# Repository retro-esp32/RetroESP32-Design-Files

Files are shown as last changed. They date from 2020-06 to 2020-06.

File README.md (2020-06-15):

# Retro ESP32
> An ESP32 Wrover based Game Boy Pocket ** Hardware Branch **



[]()

## Hardware
> FTDI Solution

Thanks to a recent contribution, we will be testing out the replacement of the CP2104 USB to UART bridge IC with an FTDI FT232RL IC

The FTDI IC is more hand solder friendly than the CP210x QFN series

Here is a teaser of what we are testing

| Top Layout | Bottom Layout |
| --- | --- |
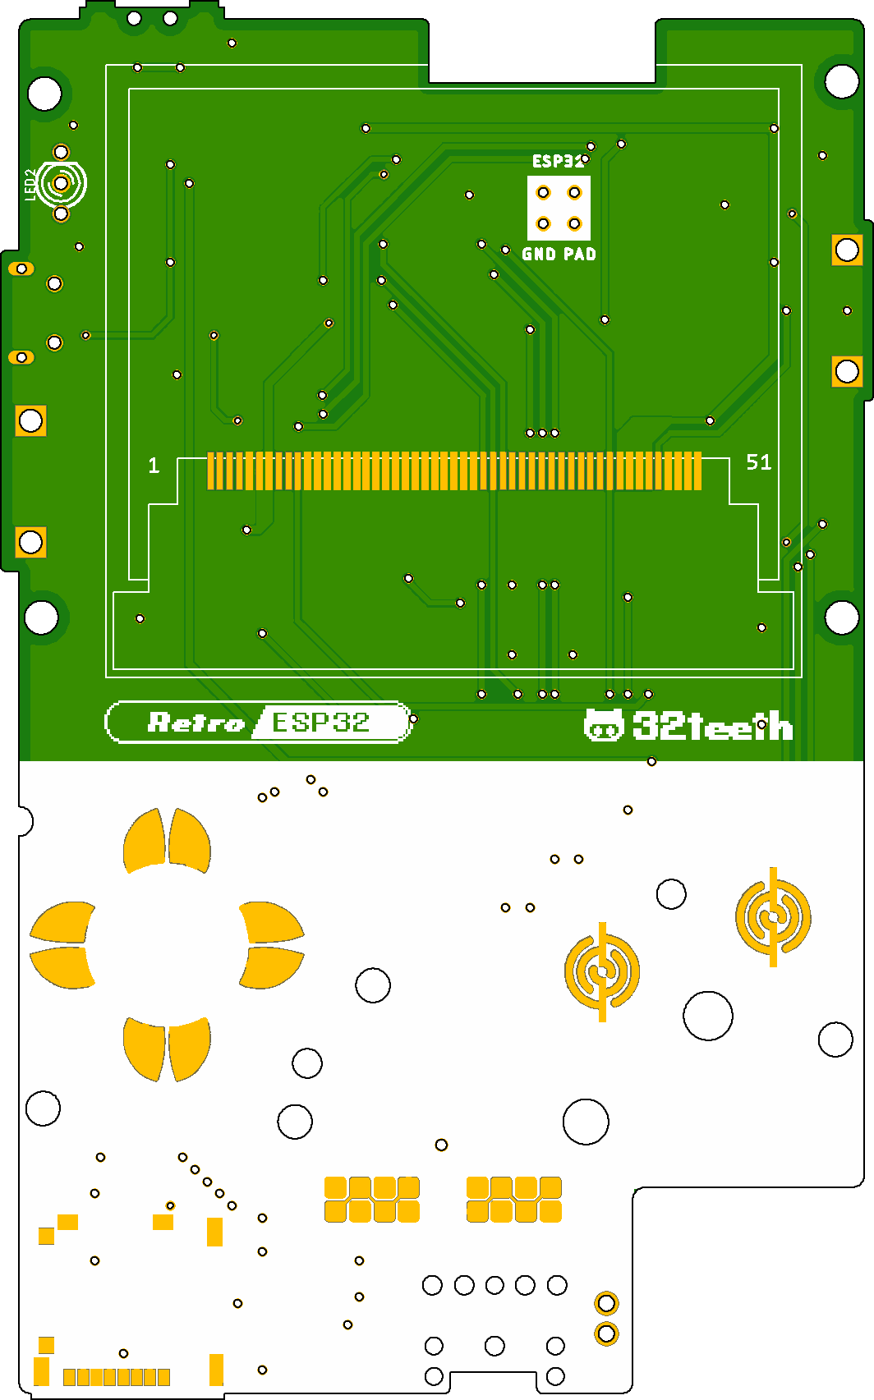
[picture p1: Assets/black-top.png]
Retro ESP32 Top
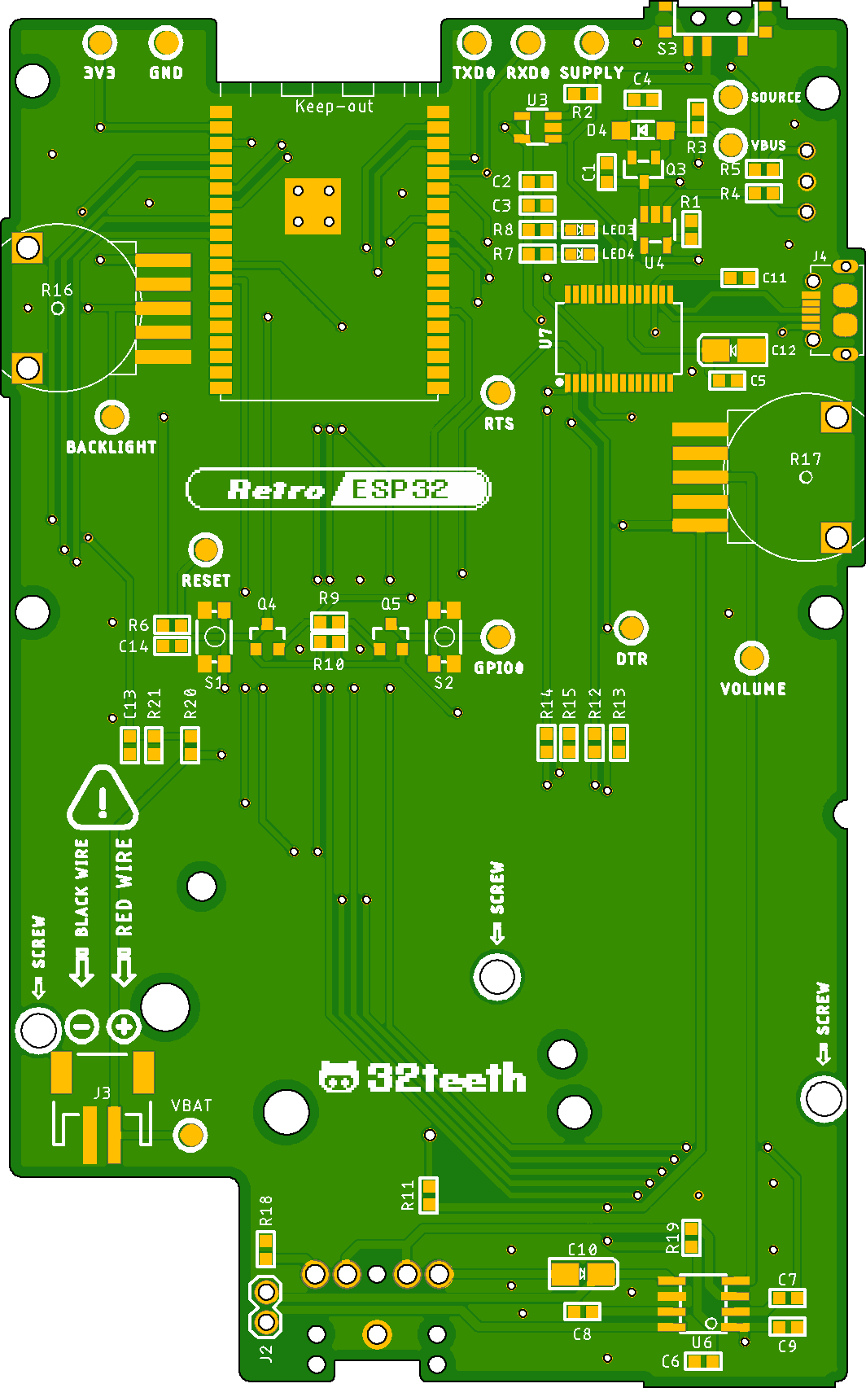
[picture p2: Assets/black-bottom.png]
Retro ESP32 Bottom
|  |  |

## Gerbers
> You can use the Gerber Files to check your production

*note:* PCB thickness must be 1mm

## BOM
> Full Bom Available

*note:* LCD and Thumbwheels have AliExpress Links

### Eagle Library
> We use a Managed Library

[RetroESP32](urn:adsk.eagle:library:12566846)

-----

> ## Although we do this for 💕 of 🕹️
> **We Also Like Coffee!**
> *Please Consider Supporting*<br>
> Support (https://github.com/sponsors/retro-esp32)

-----

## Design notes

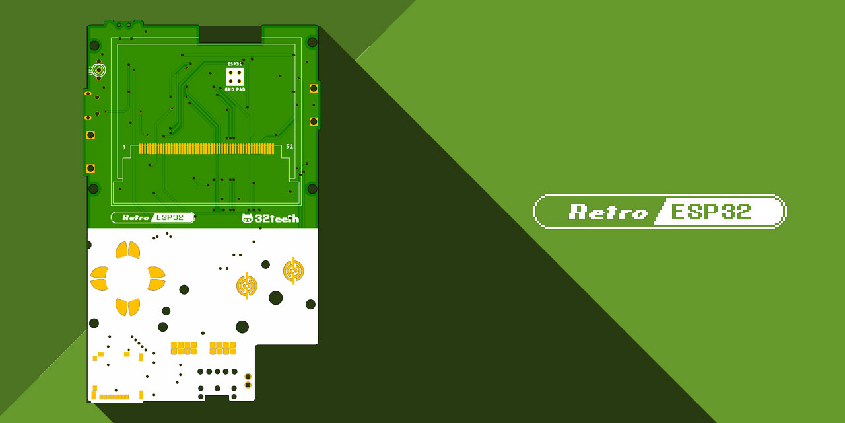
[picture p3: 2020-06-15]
Assets/hardware.jpg

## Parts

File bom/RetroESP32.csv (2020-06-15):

Quantity | Reference Designator | Manufacturer Part Number | Manufacturer | Digi-Key Part Number | Description
4 | C1, C2, C4, C6 | CL10A106MP8NNNC | Samsung Electro-Mechanics | 1276-1871-1-ND | CAP CER 10UF 10V X5R 0603
1 | C10 | F930J107KAA | AVX Corporation | 478-8152-1-ND | CAP TANT 100UF 10% 6.3V 1206
1 | C12 | F930J106MAA | AVX Corporation | 478-8151-1-ND | CAP TANT 10UF 20% 6.3V 1206
4 | C3, C8, C9, C14 | CL10A105KP8NNNC | Samsung Electro-Mechanics | 1276-1182-1-ND | CAP CER 1UF 10V X5R 0603
3 | C5, C11, C13 | CL10B104KB8NNNC | Samsung Electro-Mechanics | 1276-1000-1-ND | CAP CER 0.1UF 50V X7R 0603
1 | C7 | CL10C221JB8NNNC | Samsung Electro-Mechanics | 1276-1048-1-ND | CAP CER 220PF 50V C0G/NP0 0603
1 | D4 | MBR120LSFT1G | ON Semiconductor | MBR120LSFT1GOSCT-ND | DIODE SCHOTTKY 20V 1A SOD123L
1 | J1 | SJ1-3525NG-GR | CUI Inc. | CP1-3525NG-GR-ND | CONN JACK STEREO 3.5MM R/A
1 | J3 | S2B-PH-SM4-TB(LF)(SN) | JST Sales America Inc. | 455-1749-1-ND | CONN HEADER SMD R/A 2POS 2MM
1 | J4 | ZX62D-B-5P8(30) | Hirose Electric Co Ltd | H125272CT-ND | CONN RCPT USB2.0 MICRO B SMD R/A
1 | J5 | 5031821852 | Molex | WM12834CT-ND | MICRO SD NORMAL ULTRALOWPRO8CKTE
1 | LED2 | SSL-LX3059IGW | Lumex Opto/Components Inc. | 67-1327-ND | LED GRN/RED DIFF T-3MM TRI T/H
2 | LED3, LED4 | SML-D12M8WT86 | Rohm Semiconductor | 511-1578-1-ND | LED GREEN DIFFUSED 0603 SMD
1 | Q3 | DMG3415U-7 | Diodes Incorporated | DMG3415UDICT-ND | MOSFET P-CH 20V 4A SOT-23
2 | Q4, Q5 | MMBT2222A-7-F | Diodes Incorporated | MMBT2222A-FDICT-ND | TRANS NPN 40V 0.6A SMD SOT23-3
1 | R1 | ERJ-PA3J472V | Panasonic Electronic Components | P4.7KBZCT-ND | RES SMD 4.7K OHM 5% 1/4W 0603
1 | R18 | ERJ-PA3J151V | Panasonic Electronic Components | P150BZCT-ND | RES SMD 150 OHM 5% 1/4W 0603
5 | R2, R3, R19, R20, R21 | ERJ-PA3J104V | Panasonic Electronic Components | P100KBZCT-ND | RES SMD 100K OHM 5% 1/4W 0603
1 | R4 | ERJ-PA3J471V | Panasonic Electronic Components | P470BZCT-ND | RES SMD 470 OHM 5% 1/4W 0603
3 | R5, R7, R8 | ERJ-PA3J152V | Panasonic Electronic Components | P1.5KBZCT-ND | RES SMD 1.5K OHM 5% 1/4W 0603
8 | R6, R9, R10, R11, R12, R13, R14, R15 | ERJ-PA3J103V | Panasonic Electronic Components | P10KBZCT-ND | RES SMD 10K OHM 5% 1/4W 0603
2 | S1, S2 | KMR221GLFS | C&K | 401-1427-1-ND | SWITCH TACTILE SPST-NO 0.05A 32V
1 | S3 | MA12RTR | APEM Inc. | 679-1847-1-ND | SWITCH SLIDE SPDT 300MA 4V
1 | U1 | ESP32-WROVER (16MB) | Espressif Systems | 1904-1015-1-ND | WIFI MODULE 128MBITS SPI FLASH
1 | U3 | AP2112K-3.3TRG1 | Diodes Incorporated | AP2112K-3.3TRG1DICT-ND | IC REG LINEAR 3.3V 600MA SOT25
1 | U4 | MCP73831T-2ACI/OT | Microchip Technology | MCP73831T-2ACI/OTCT-ND | IC CONTROLLR LI-ION 4.2V SOT23-5
1 | U6 | LM4875MX/NOPB | Texas Instruments | 296-35282-1-ND | IC AMP AUDIO PWR 1W MONO 8SOIC
1 | U7 | FT232RL-REEL | FTDI, Future Technology Devices International Ltd | 768-1007-1-ND | IC USB FS SERIAL UART 28-SSOP
2 | R16, R17 | 10K |  |  | Gameboy Pocket Volume (10K Potentiometer) | https://www.aliexpress.com/item/32830491244.html
1 | U5 | TFT-DISPLAY-2.6-51PIN |  |  | TFT-DISPLAY-2.6-51PIN 2.6 inch TFT liquid horizontal screen ILI9342 3/4 line SPI MCU8 bit 16 touch | https://www.aliexpress.com/item/32827359467.html

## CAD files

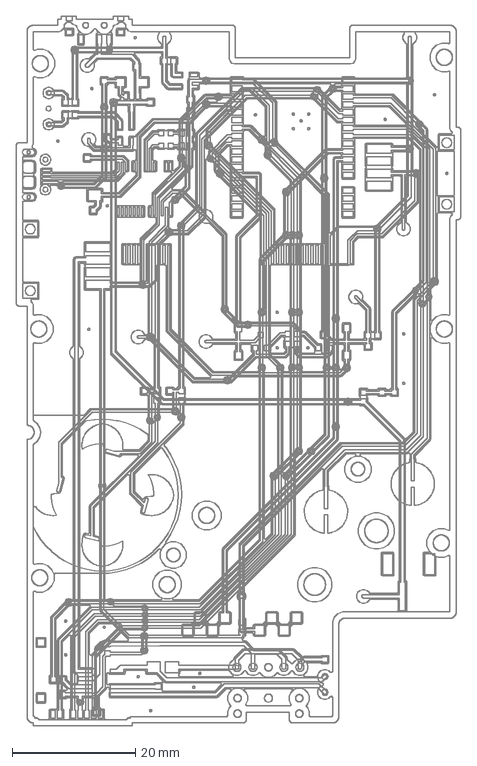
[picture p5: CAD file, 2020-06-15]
dxf/RetroESP32.dxf
72.0 x 115.0 mm

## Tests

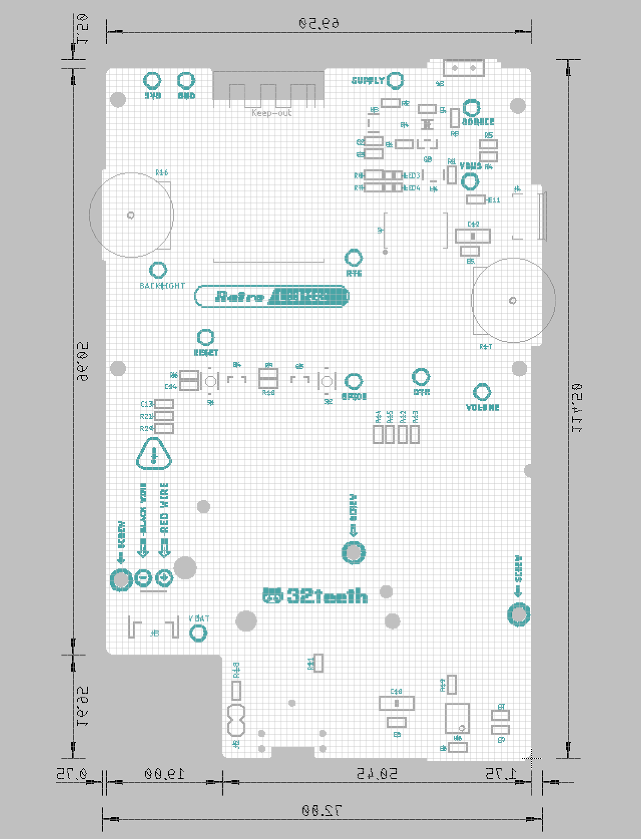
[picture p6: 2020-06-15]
Assets/MeasurementsBottom.png

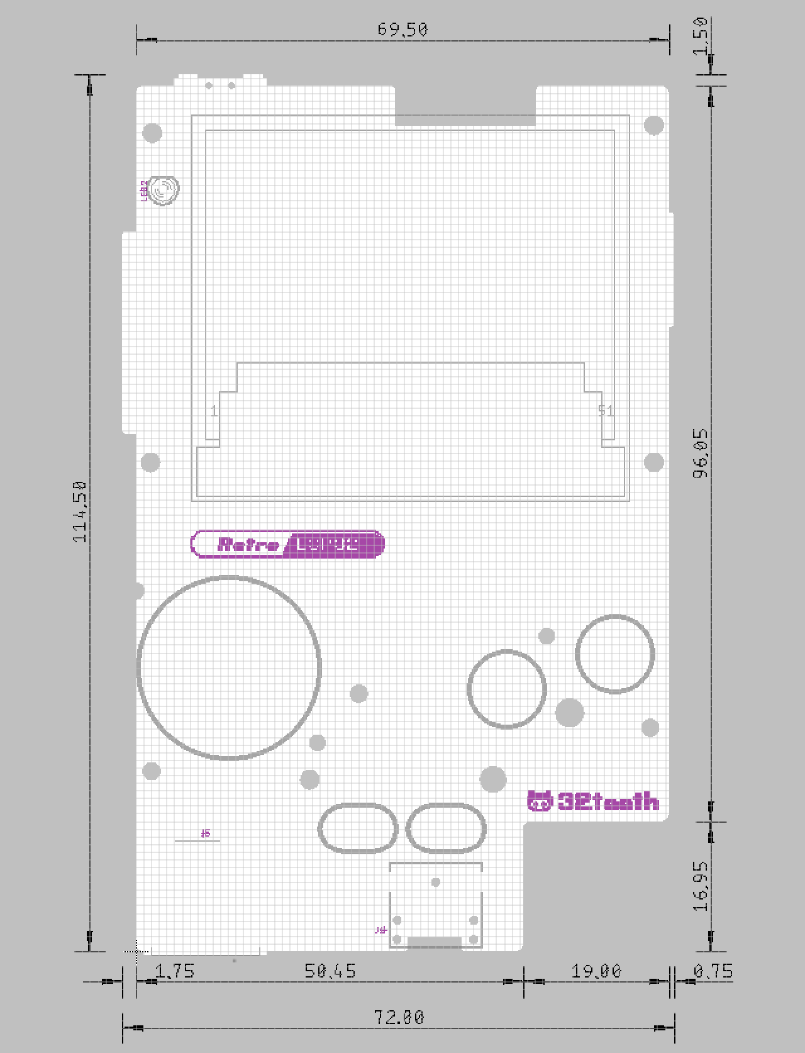
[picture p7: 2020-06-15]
Assets/MeasurementsTop.png

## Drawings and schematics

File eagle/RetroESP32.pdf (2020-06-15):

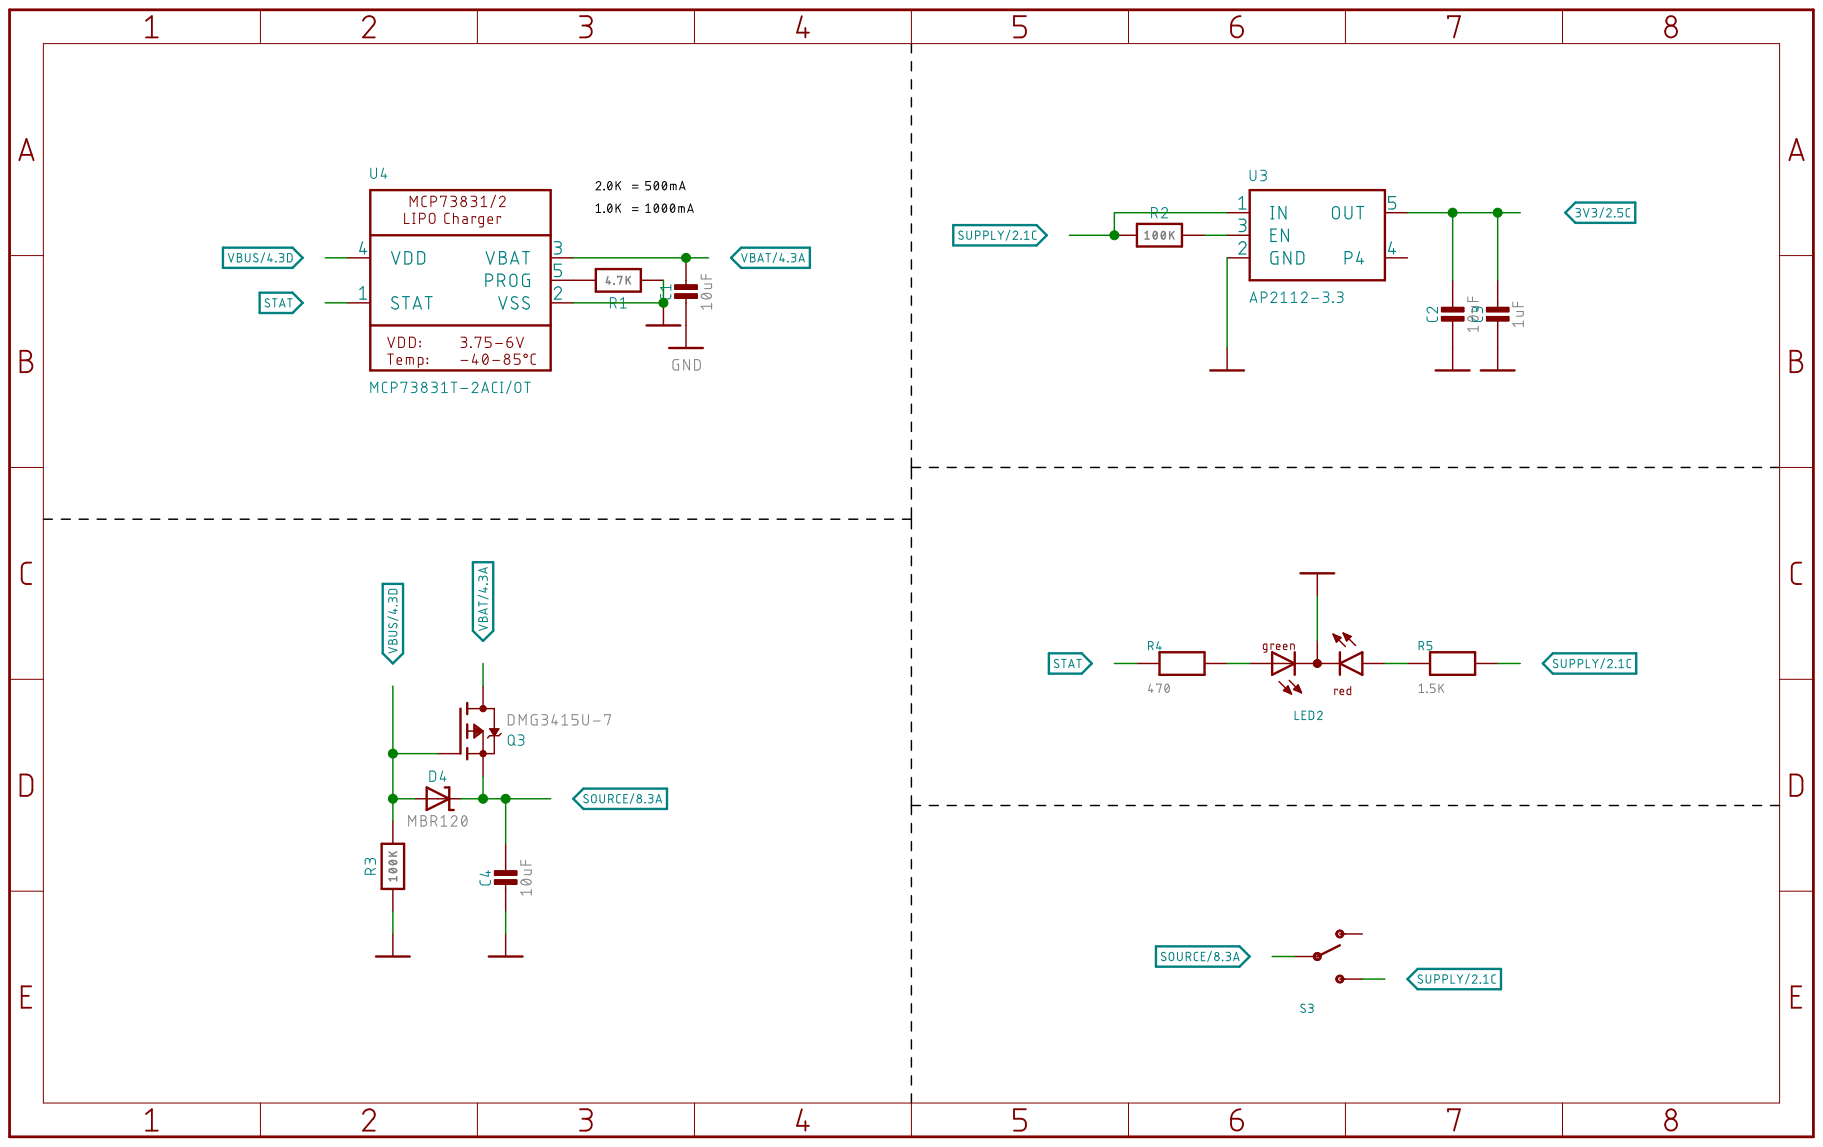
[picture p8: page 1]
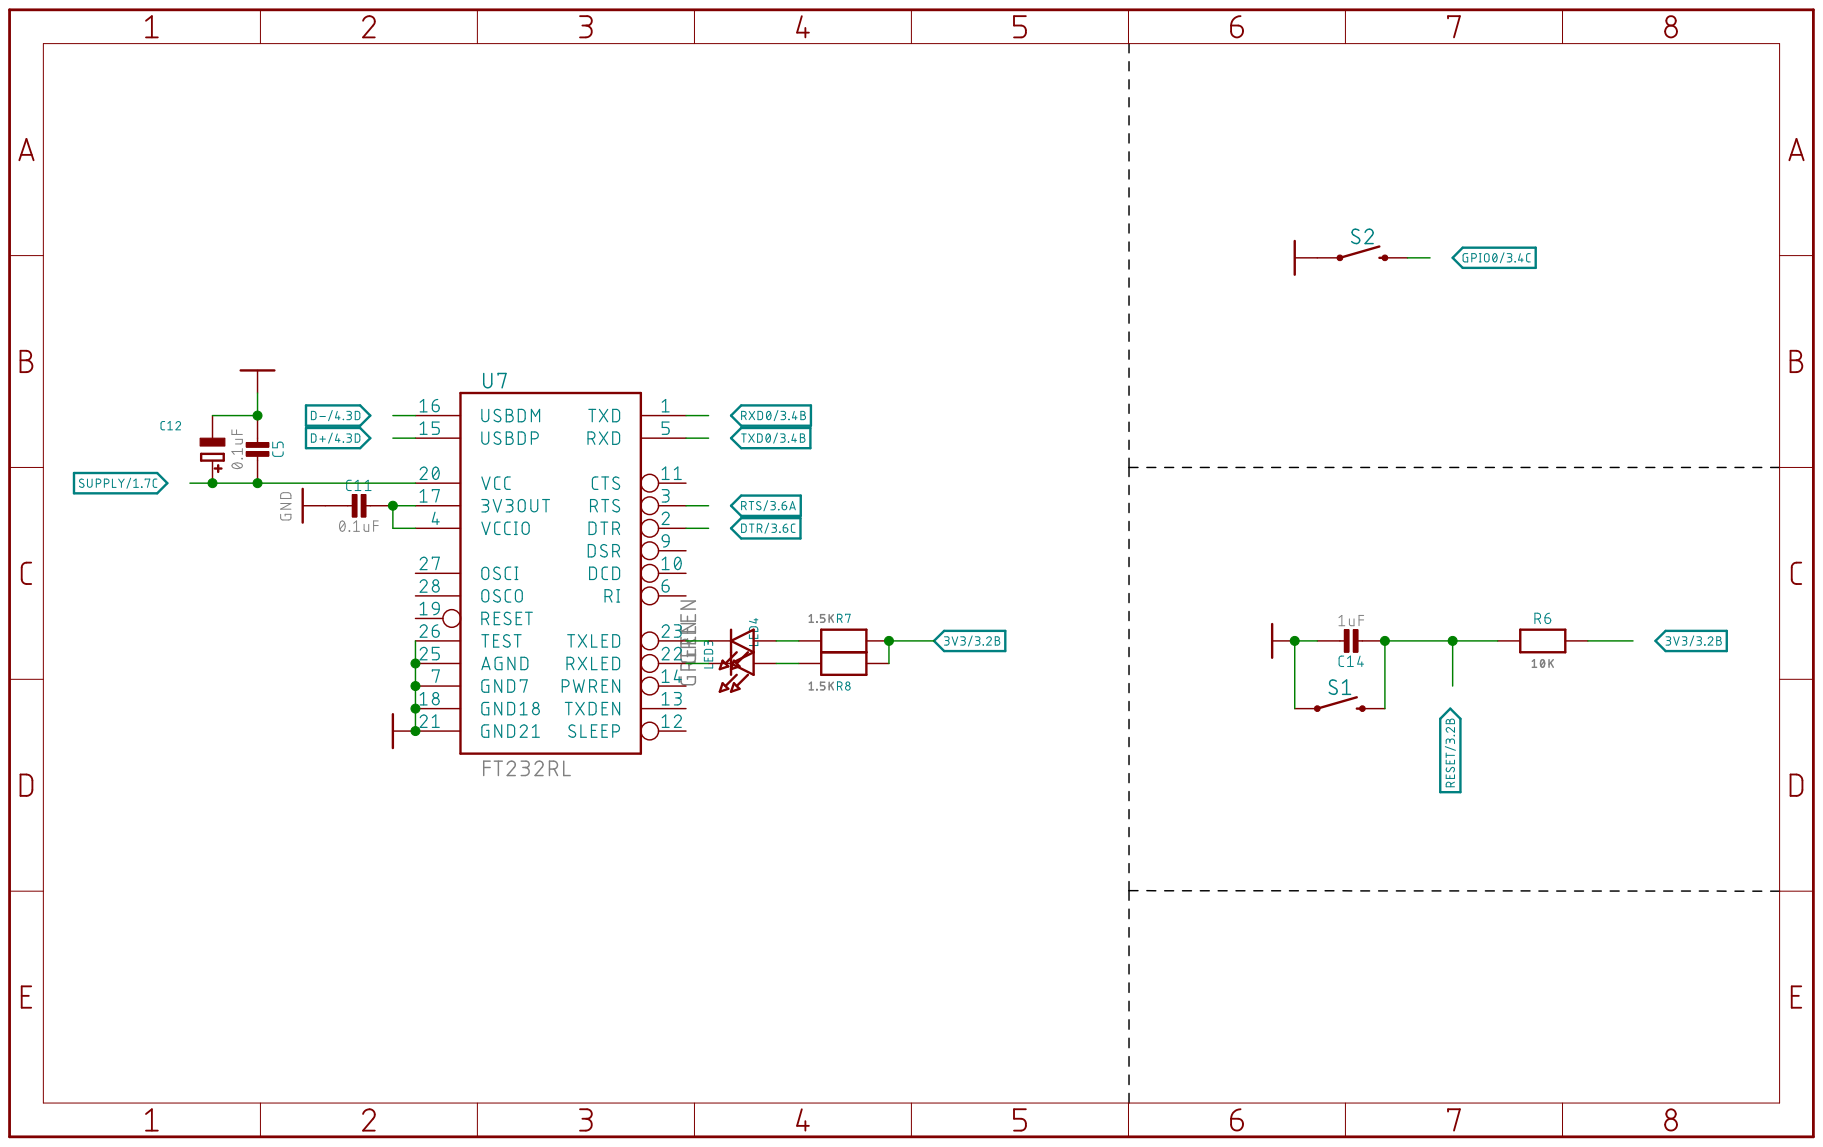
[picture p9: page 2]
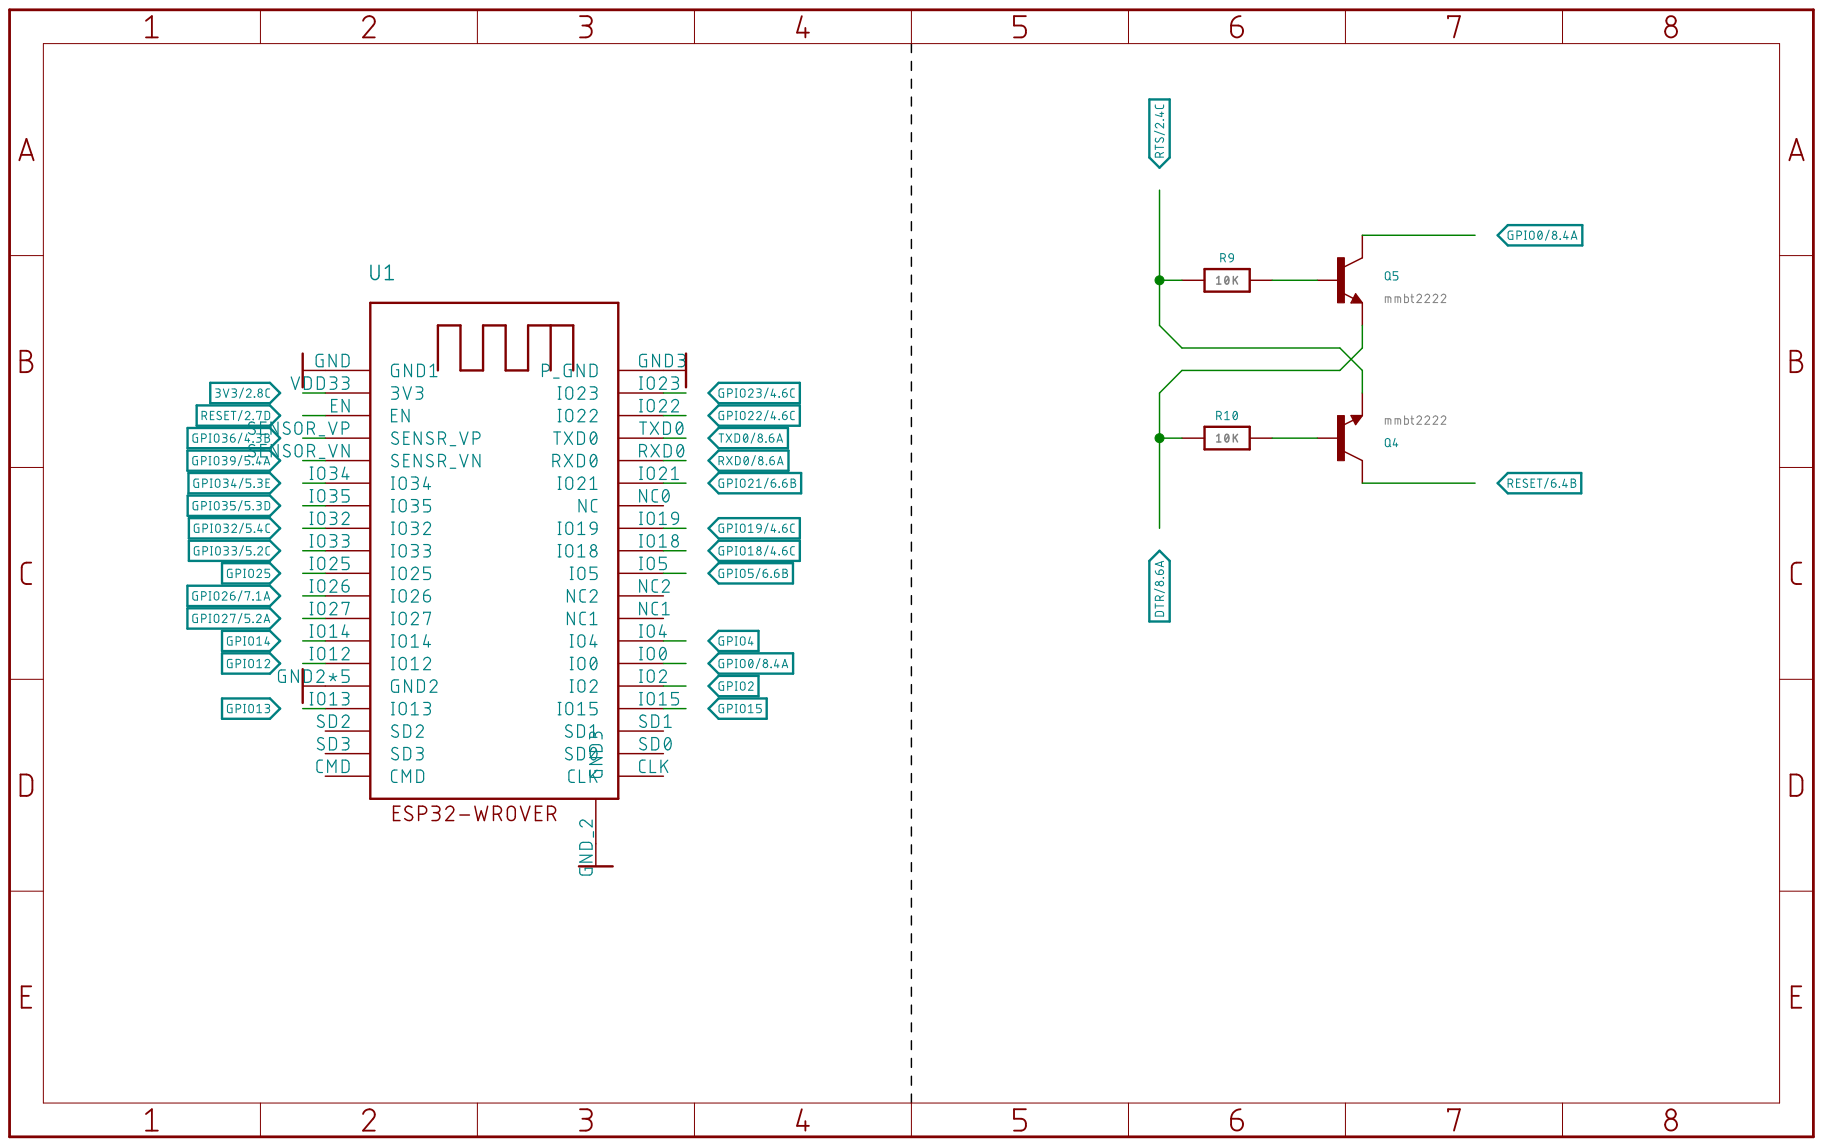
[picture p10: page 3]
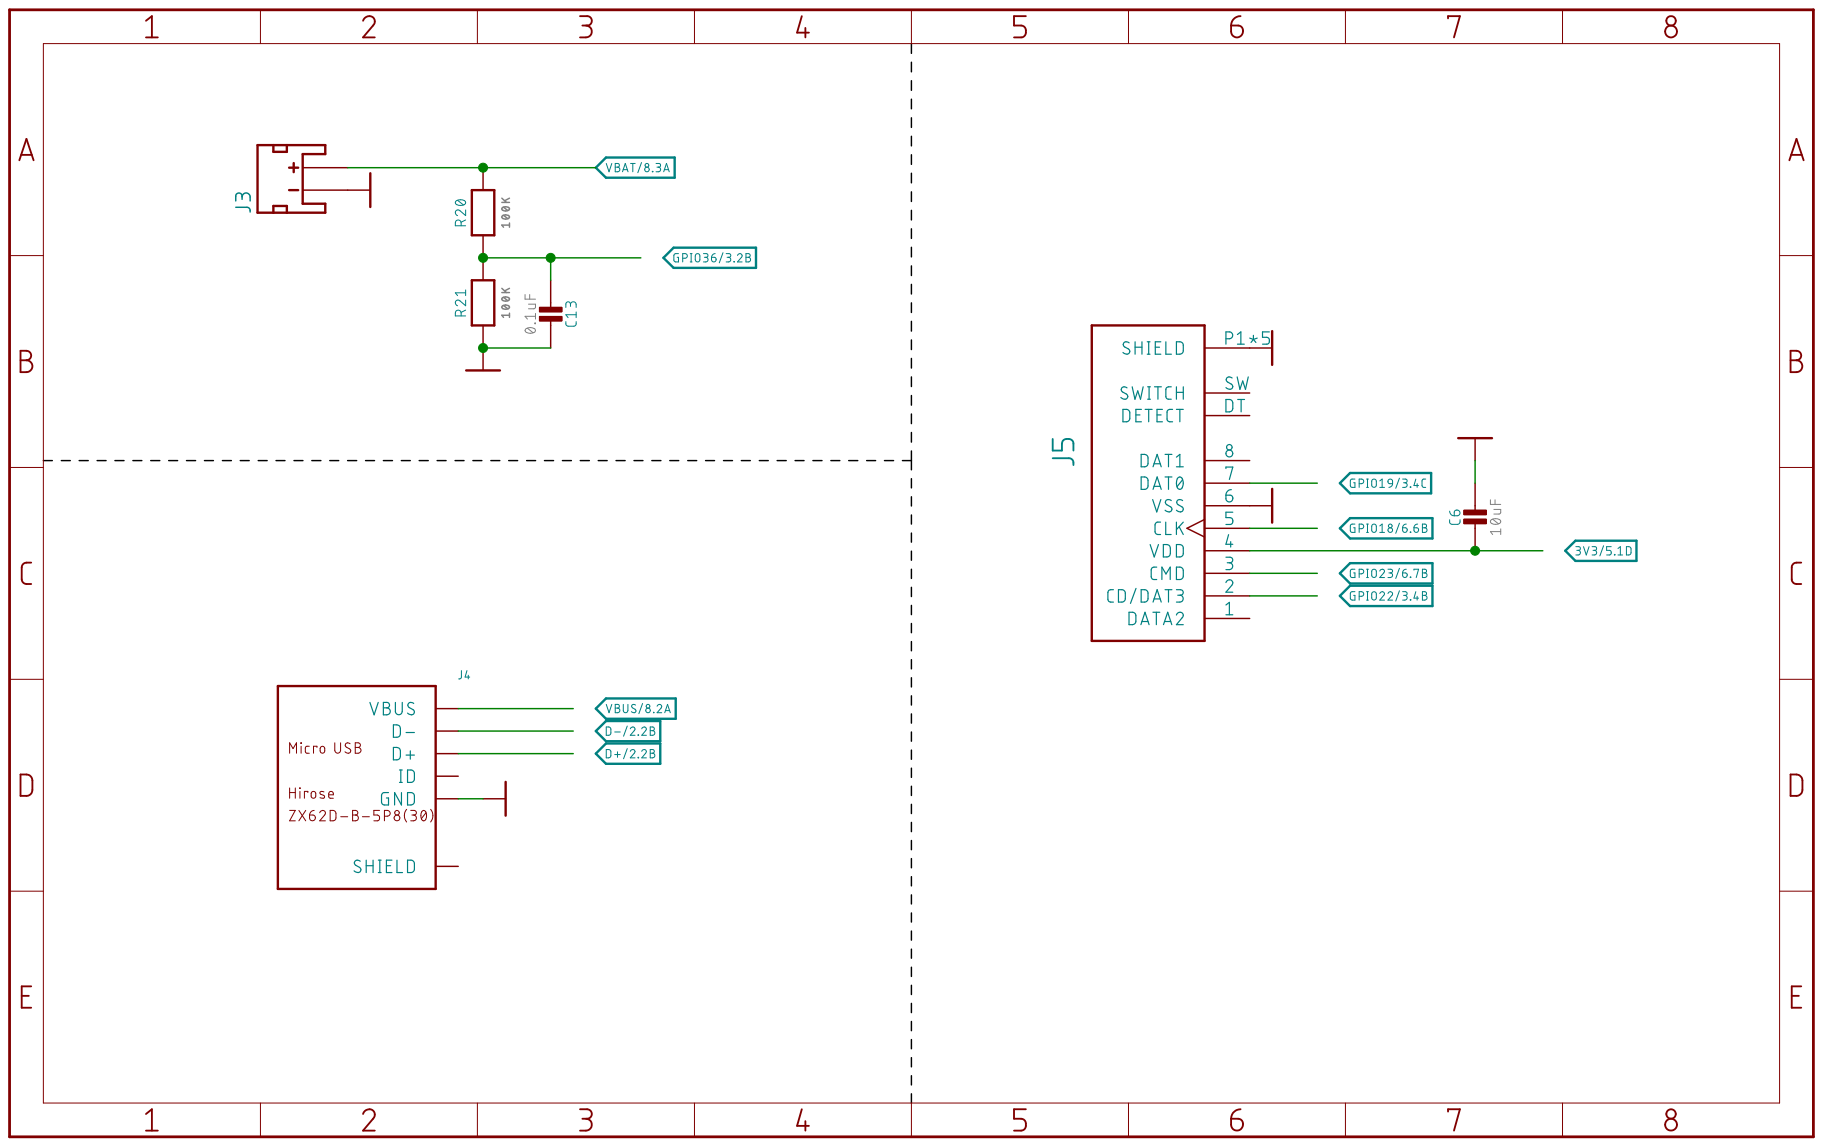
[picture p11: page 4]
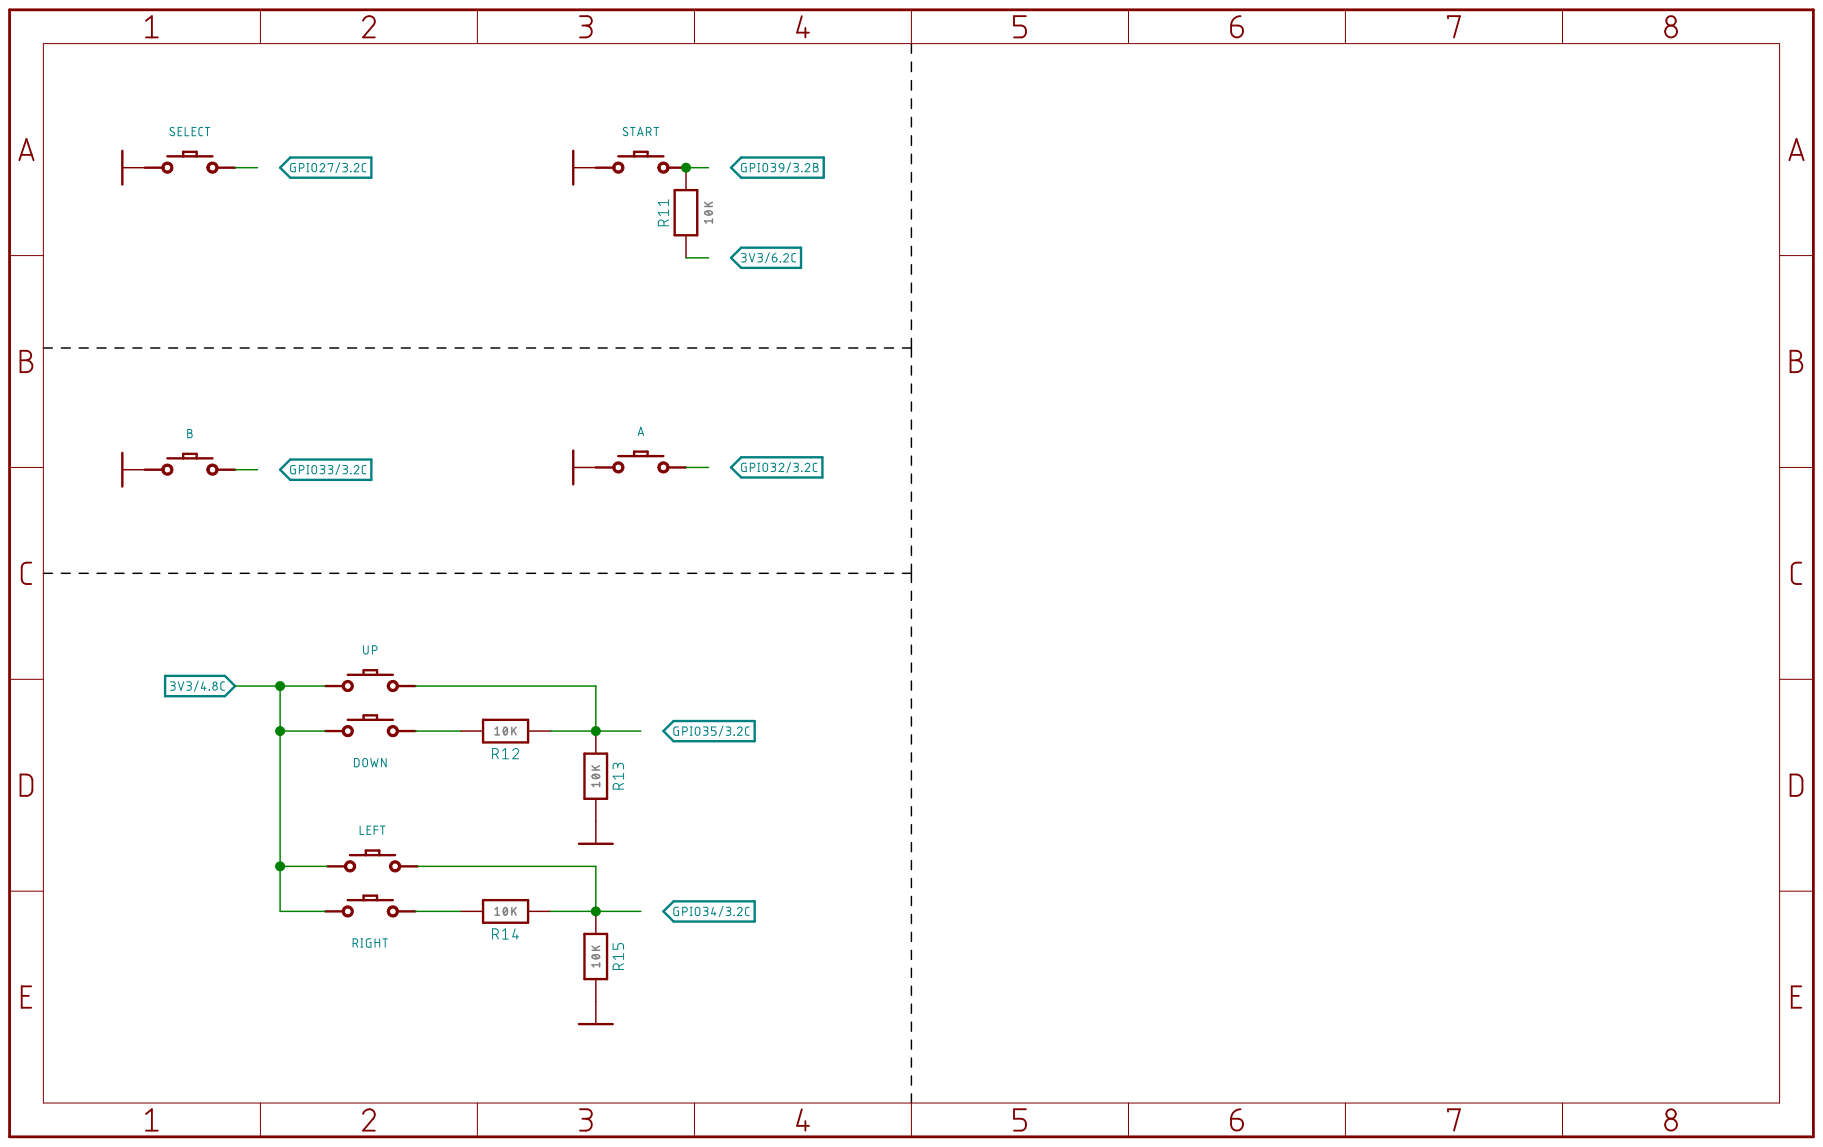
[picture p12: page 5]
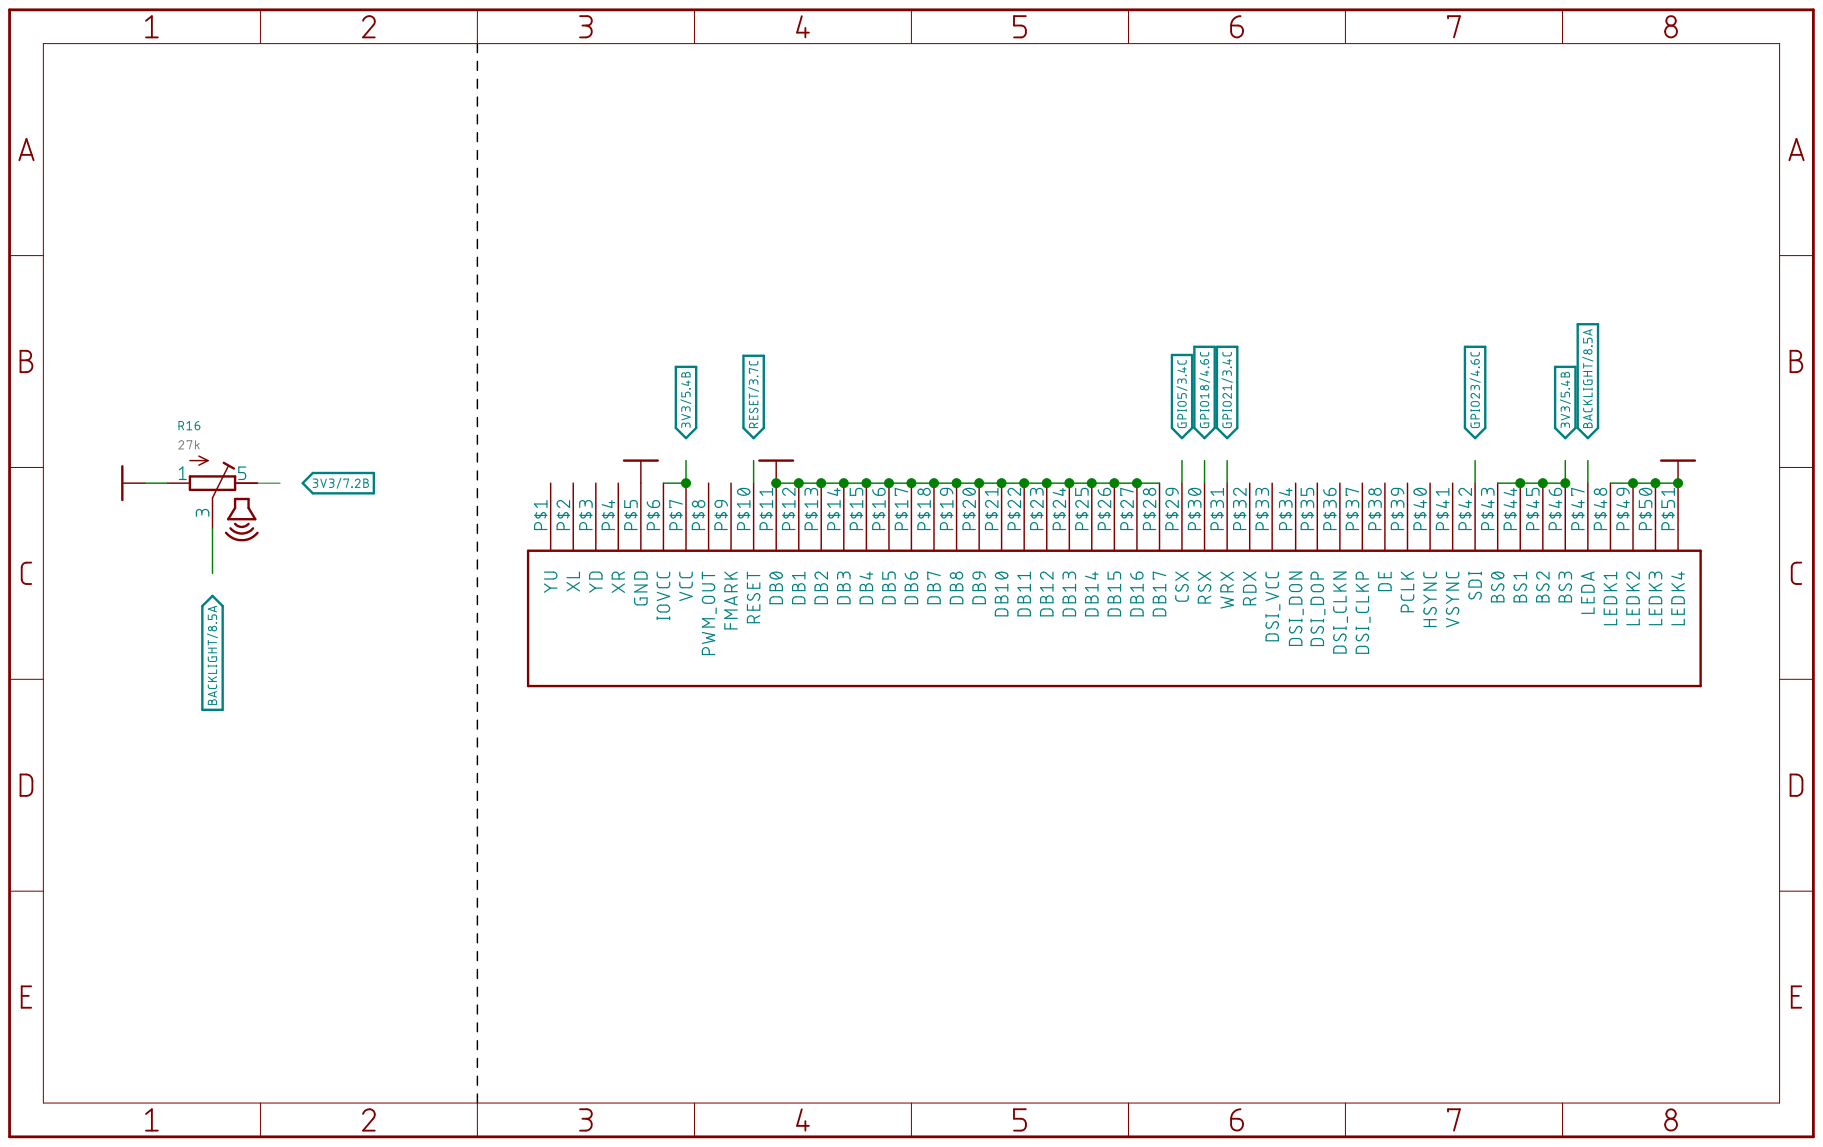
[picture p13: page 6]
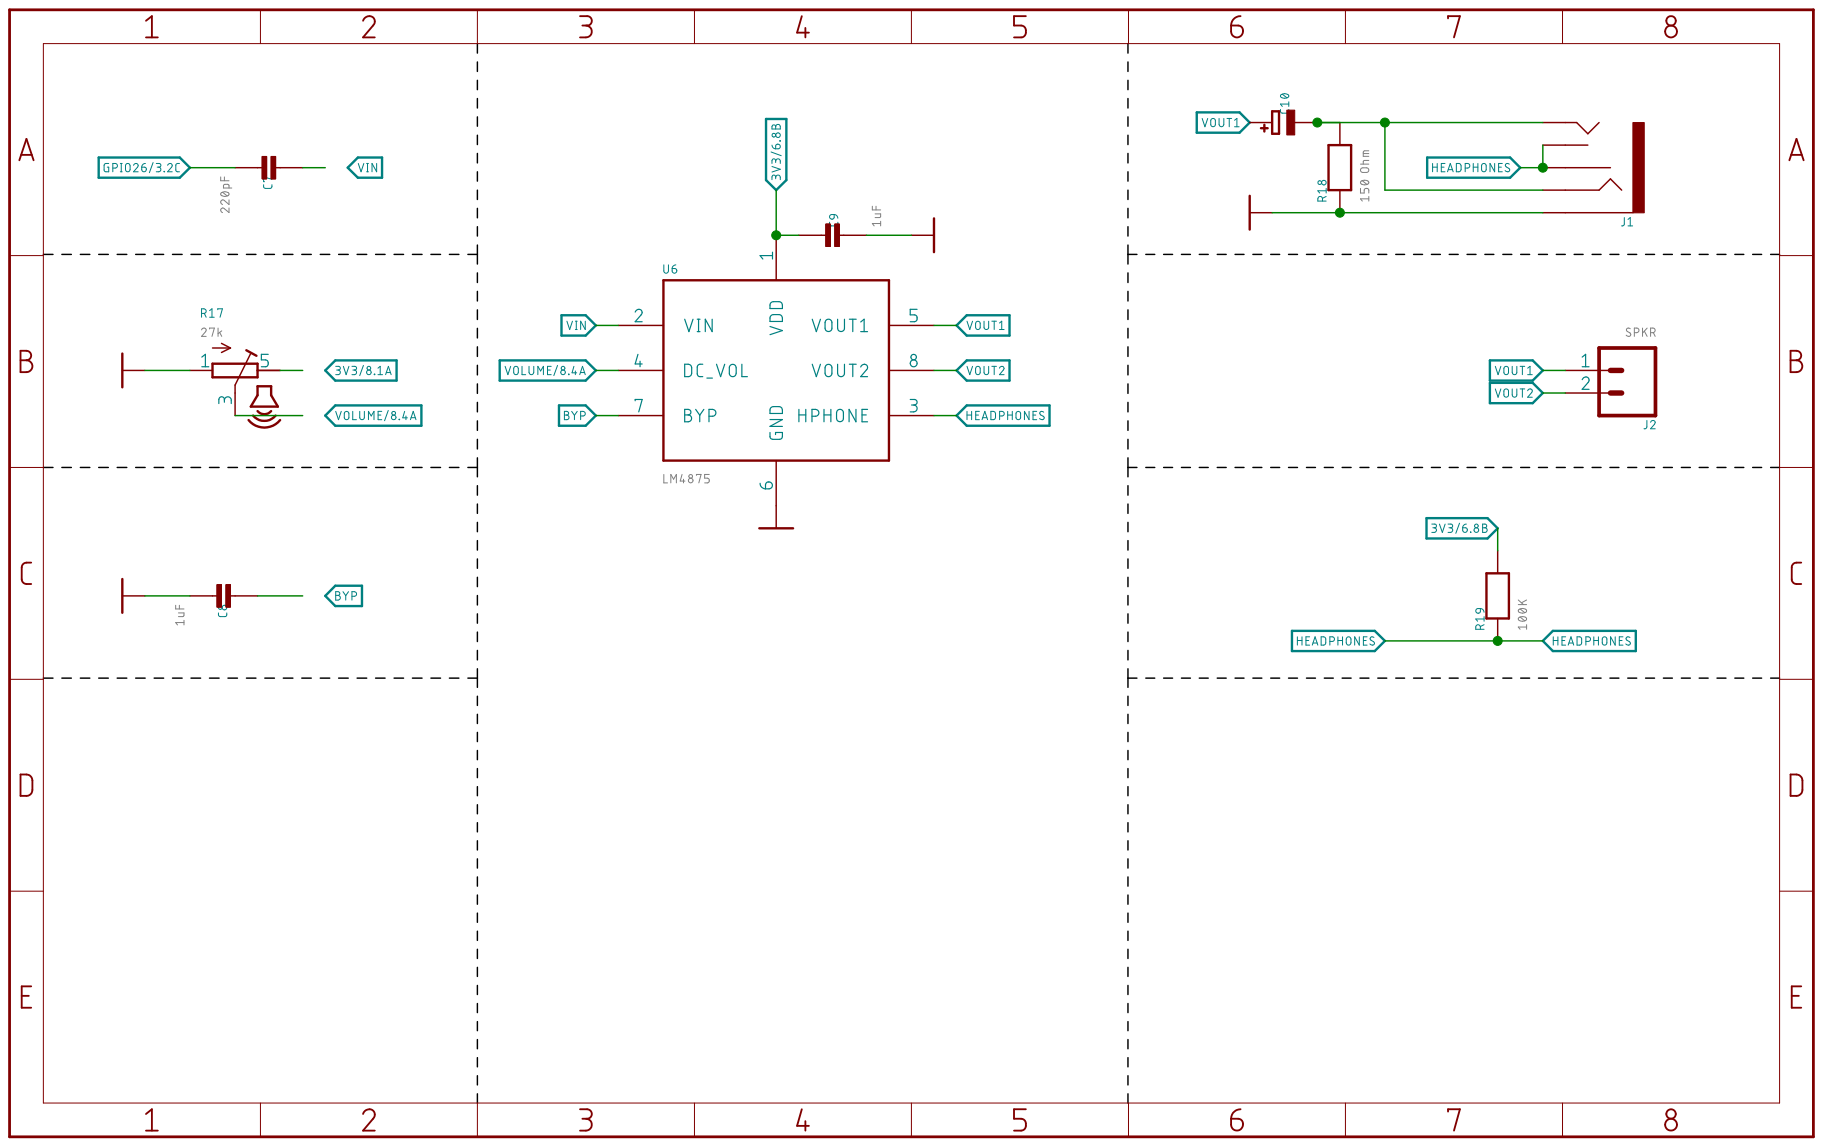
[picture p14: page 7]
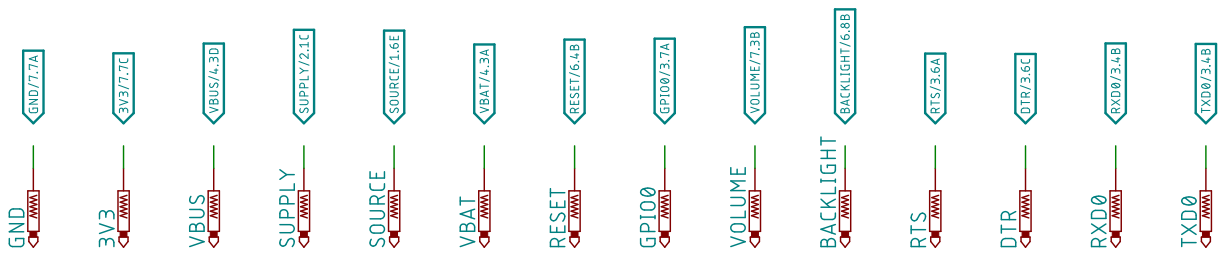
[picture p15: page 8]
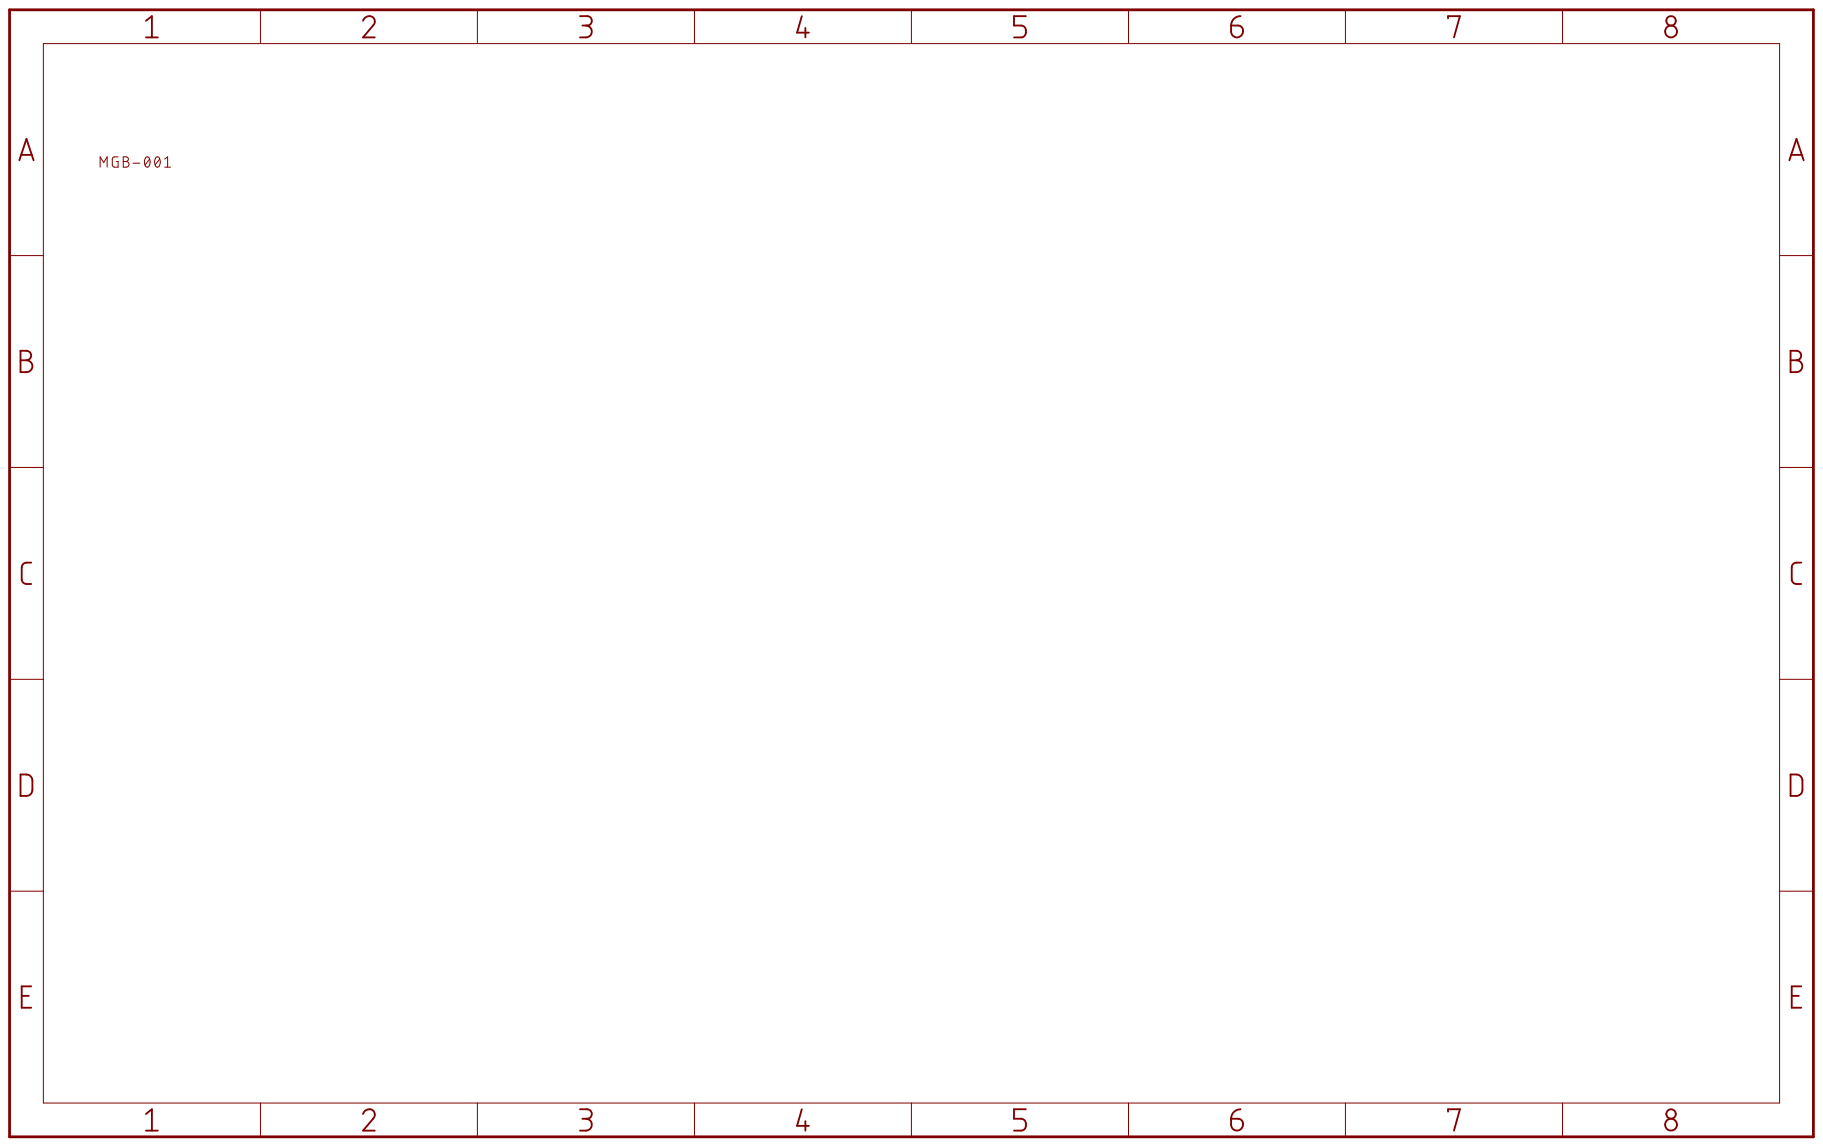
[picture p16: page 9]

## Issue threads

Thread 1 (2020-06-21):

[question] board processing issue on jlcpcb site

fizarum, 2020-06-21:
**Is your feature request related to a problem? Please describe.**
First of all: I think its not a problem of board design but limitation of mentioned pcb service and I'm trying to solve it, any advices are welcome :)

There is an issue with processing gerber files (top side) on [JLCPCB](https://jlcpcb.com/) - the top silck screen overlaps top solder mask:
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
 Looks like its a limitation of this service and final board may be produced with issues. For example
[OSHPARK](oshpark.com) doesnt have this issue:
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
but more expensive ($64.30 on OSHPARK and $6.40 on JLCPCB)

**Describe the solution you'd like**
I know there are some older designs which have another silck screen, for example [here](https://github.com/airainchoc/RetroESP32/tree/Hardware) I've found:
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
So is it possible to add gerber files with older design as _compatible-with-cheap-pcb-service-solution_?

**Describe alternatives you've considered**
Or, if its possible, put some list of trusted (tested?) pcb services to make this board without such issues

32teeth, 2020-06-22:
### Hi there
Thanks for getting in touch

i am not familiar with JLCPCB, seems that this may be  an issue with the gerber viewer.\
take a [look here](https://gerber-viewer.easyeda.com/showcase/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). this is a generic gerber viewer that most pcb shops use

here is an example of the output
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

below is a list of pcb houses previously used

- All PCB
- PCB Mart
- Seeed Studio

When you do order, ensure you select

- 1mm thickness
- gold enig (best solution for silicon buttons)

-----

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

-----

Closed 2020-06-22.

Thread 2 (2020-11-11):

You can update the ili9342c 45pin design file？

jianjinliao, 2020-11-11:
Hi，Last time I discussed the screen of ili9342 with you. You said that the 9342c design file was updated. I am looking forward to building it。

32teeth, 2020-11-11:
hi @jianjinliao
please understand this is a hobby
i am working on it and there are a few more things to test

if you would like to accelerate the process
i strongly recommend sponsorship or endorsement

[Endorse 32teeth](https://github.com/sponsors/32teeth)
[Endorse Retro ESP32](https://github.com/sponsors/retro-esp32)

Closed 2020-11-11.
